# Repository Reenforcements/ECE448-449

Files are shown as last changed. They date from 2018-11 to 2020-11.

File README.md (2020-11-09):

# Reconfigurable Pinball Machine

#### [Final_Report.pdf](https://github.com/Reenforcements/ECE448-449/blob/master/Final_Report.pdf)

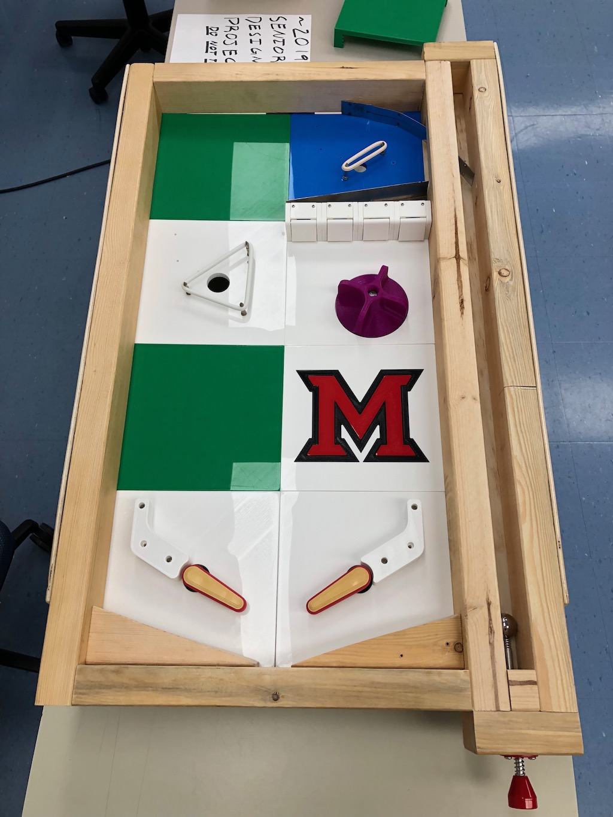
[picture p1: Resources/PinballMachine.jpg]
Pinball machine


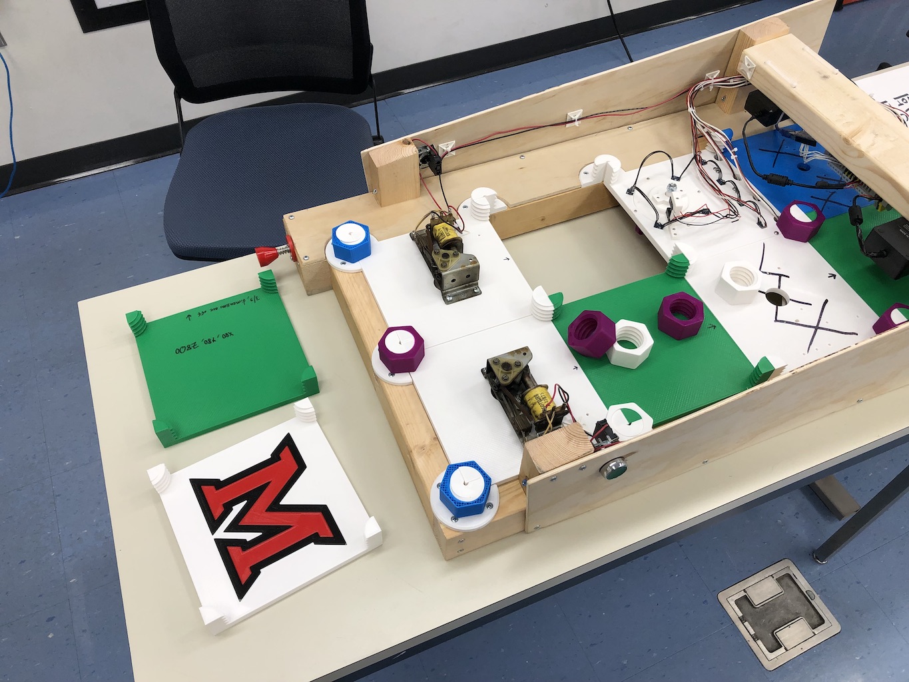
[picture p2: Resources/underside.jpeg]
Underside of the machine


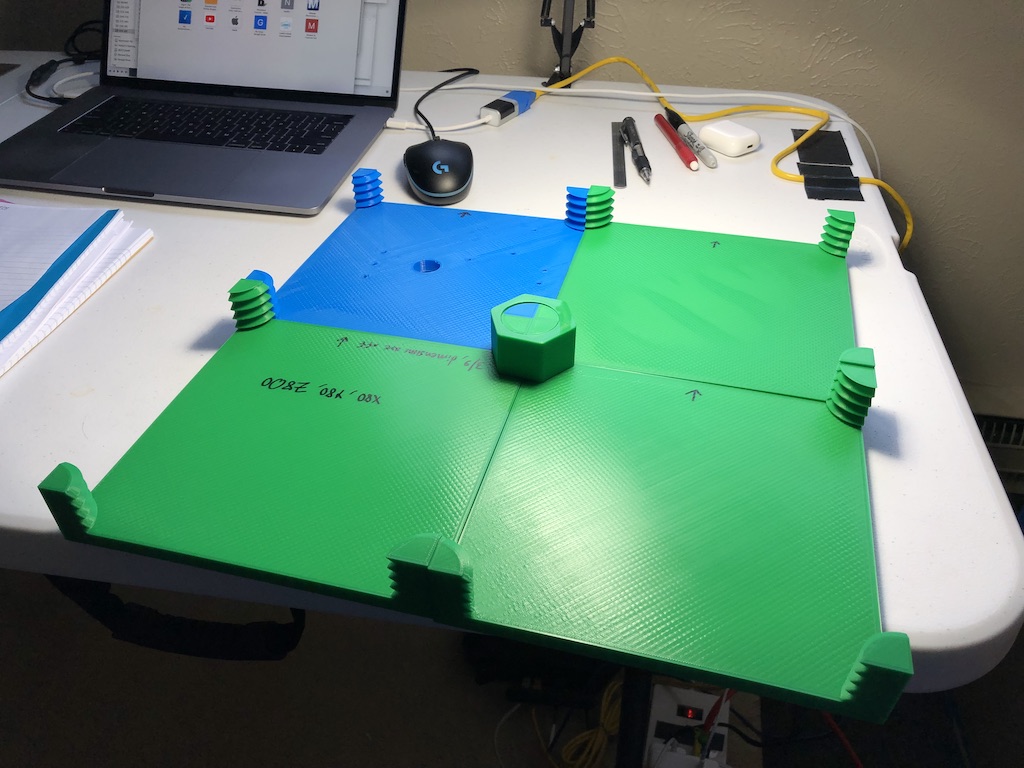
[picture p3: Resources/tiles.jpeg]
Tile connectivity


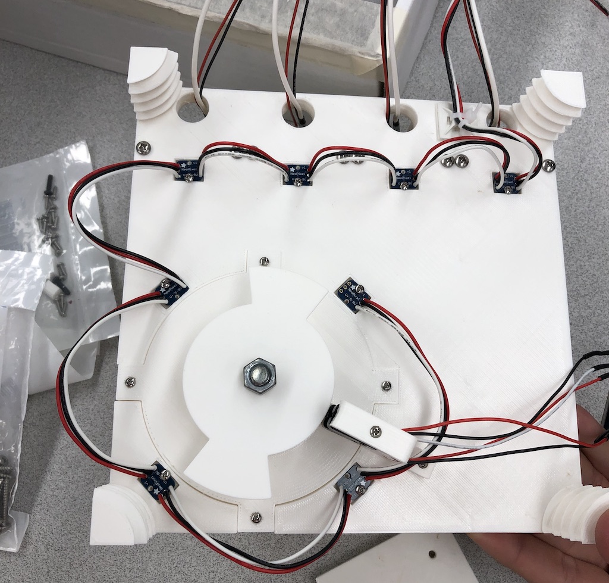
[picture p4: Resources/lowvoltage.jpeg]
Low voltage tile


This is a research project for a reconfigurable pinball machine for senior design at Miami University.

#### Team Members:
- Austyn Larkin
- Kyle Nichols
- Scott Nicholson
- Storm Nicholson

#### Adviser:
Dr. Jamieson

## CADFiles

The CADFiles folder holds 3D printable STL files of the current CAD design.

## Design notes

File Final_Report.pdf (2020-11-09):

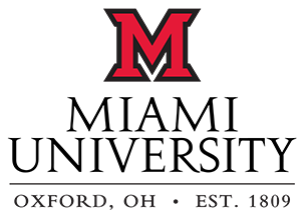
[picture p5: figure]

## Pinball Machine Design Project ECE 449

## Austyn Larkin Kyle Nichols Scott Nicholson Storm Nicholson

## Advisor: Dr. Jamieson

### 1. Intro/Problem Definition

Pinball machines are a type of arcade game. In pinball, the goal for the player is to

control the ball with flippers at the bottom of the play field. Each element in the game has a

specific point value associated with it. When the ball hits/touches/rolls over the scoring point,

that specific amount is added to the players overall score. Pinball machines cost thousands of

dollars to build and because of the fairly static play area, they can suffer from poor replayability.

The goal of this project is to design a reconfigurable pinball/arcade machine. The

question is; how reconfigurable can the machine be and what tools are needed to create the

framework for such a machine. Reconfigurable can mean many different things. Some of the

options discussed were changing the playfield in between games, changing the playfield while

the game is being played, and having different game modes within a menu. These ideas will

allow the game to be changed either physically and/or electronically to alter gameplay. From a

player’s perspective, this will help to keep the game fresh and new. From an arcade owner’s

perspective, reconfigurability enhances replayability at minimum cost, thus increasing revenue.

### 2. Project Background

A pinball machine consists of (at minimum) the following components: pinballs, flippers,

a plunger, and a play area with scoring points and for the ball to roll around on, bump into,

activate, etc. The play area contains a variety of play elements to enhance gameplay such as:

bumpers, lights, targets, holes, and carousels. Each of these components is described in detail

below.

- Pinballs (Figure 2.1) are metal spheres with a nominal diameter of 1 ” and ¹
16
weigh 2 oz. They’re used as the main playing piece in the game. 8

7

Figure 2.1 - A Pinball

https://www.amazon.com/WE-Games-Replacement-Steel-Pinball/dp/B004AA2ZD6

- Flippers (Figure 2.2) are levers which are controlled by the player, to hit the ball

in the direction desired by the player. Each flipper is covered in rubber so that the

pinball bounces off of it and is controlled by a button on the side of the machine.

The buttons activate solenoids underneath the playfield, which move the flippers.

The flippers in our design require a 24V 5A DC power supply as per specs found

on the manufacturer's website.

Figure 2.2 - Pinball Flippers

https://pinside.com/pinball/machine/f-14-tomcat

- The plunger (Figure 2.3) is used by the player to launch a new ball into the play

area. The plunger consists of a handle that is pulled outwards towards the player.

Pulling the handle out stretches a spring around the plunger’s axle. When the

player releases the plunger, the spring recoils and launches the ball located in

front of it into the play area.

Figure 2.3 - Pinball Plunger

https://www.pinballlife.com/stern-ball-shooter-assembly.html

- The playfield is defined as the region in which the pinball moves (Figure 2.4). It

contains the flippers as well as other play elements mentioned above. To keep the

game going, the player has to ensure the ball doesn’t leave the playfield.

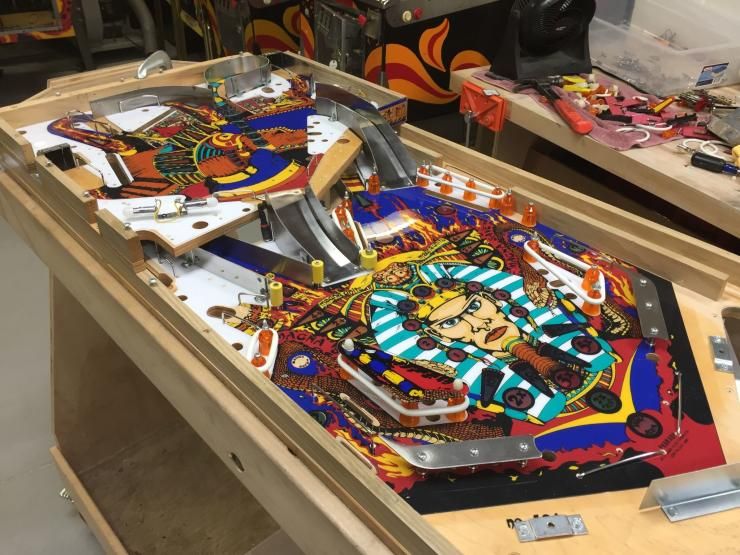
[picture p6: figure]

Figure 2.4 - The Pinball Playfield

http://www.pinballgifts.com/store/p75/Pinball_Playfield_Hardtop.html

- Bumpers come in multiple styles and include solenoids that use an array of

different voltages. An example of a circular pop bumper is shown in Figure 2.5. If

the pinball makes contact with the lower ring of the bumper, the solenoid is

activated. The solenoid pulls the upper ring of the bumper down onto the pinball

which causes the ball to ricochet away from the bumper.

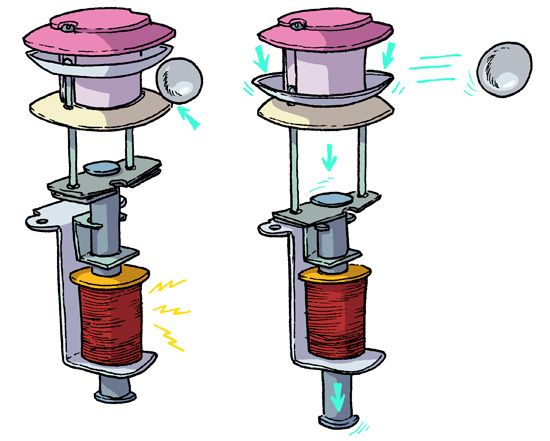
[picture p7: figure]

Figure 2.5 - An illustration of how a pop bumper works

http://droptargetzine.blogspot.com/2013/02/revisited-illustration-4-pop-bumper.html

### 3. Project Research

The first step in making our reconfigurable pinball machine was to define what

reconfigurable meant. In our case, we defined reconfigurable to be, any change to the machine in

order to alter the gameplay. In theory, this could be done both physically and through software.

We decided to explore the physical route, meaning that we would try to design a machine in

which the playfield could be rearranged, changed or entirely replaced.

To accomplish this, the play area is divided into a grid of tiles. Each tile would be a

square of material (either wood or 3D printed). Each tile contains its own unique set of play

elements. Tiles are joined together to ensure the ball rolls smoothly across the joints. The tiles

could be easily detached from one another to allow them to be interchanged. As each tile is

unique, the interchanging of tiles would allow the owner to alter how game looks and is played.

An early sketch of a single tile is shown in Figure 3.1.

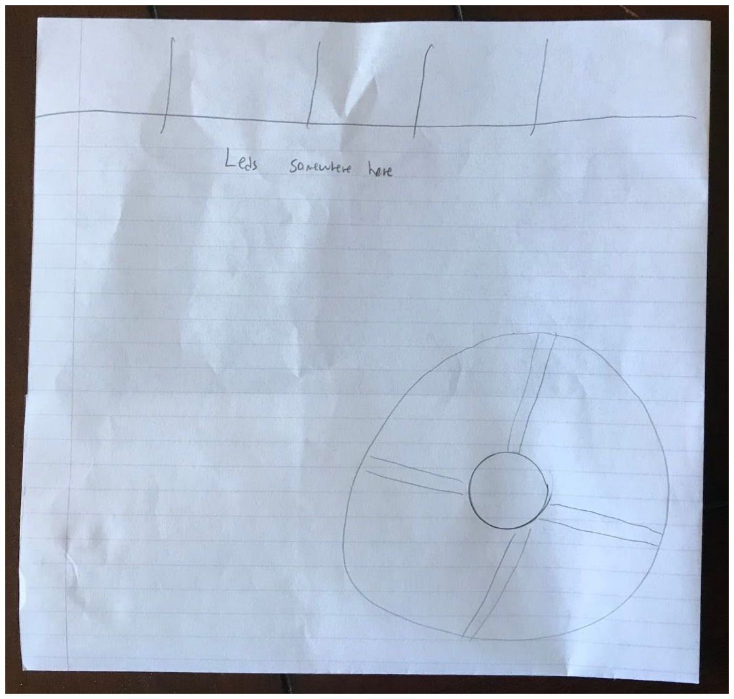
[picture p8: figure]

Figure 3.1 - An early sketch of a single tile

The tile in Figure 3.1 has three separate play elements. The circle in the bottom right

corner is the carousel. As the carousel spins, points could be added to the player’s score, thus the

goal is to keep the carousel spinning for as long as possible. The divisions at the top were coined

“bingo boxes”. These boxes have doors on the front that when hit by the ball, trigger the switch inside. LEDs are embedded throughout the tile to give feedback to the player. To create a fully

reconfigurable pinball machine, a variety of these tiles could be created and linked together to

form the playfield. As long as the tiles are kept to our specified size of 20x20cm, they can

contain any play elements in any combination.

This tile based system poses several potential issues such as ensuring the tiles link

together smoothly. If the height of the surface of one tile does not match up with the others, then

the pinball would not be able to roll smoothly across them. Another issue is, how do we actually

link multiple tiles together? Tiles would need to be linked together tightly to prevent shifting

during gameplay.

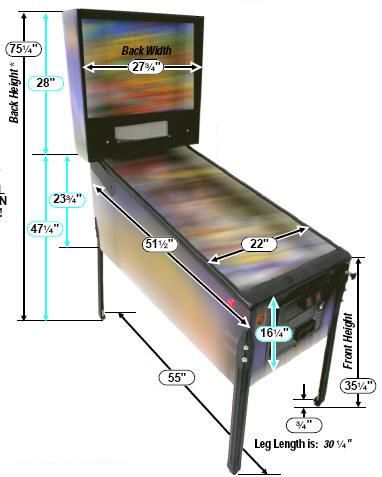
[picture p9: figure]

Figure 3.2 - Common Machine Dimensions

http://www.castleclassicarcade.com/archives/game-dimensions

When researching the components for this project, we found that the cost of building a

full size machine would put us way over our $150 budget. The full size budget is determined by

using the dimensions in Figure 3.2 (above). Once we had the dimensions, we were able to

estimate the amount of tiles a full machine would need to include, which would be around 20.

We estimated the average cost of making a basic tile to be approximately $45. A basic tile

included the cost of one or two playfield elements, screws, wiring and the material of the tile

itself.

After totaling the cost for a full size machine, the decision was made to scale our design

back. We decided that building a single basic tile, like the one previously described, as a demo

was a more achievable task. Doing such would keep us within budget and would also give us a

chance to prove that we are capable of replicating the demo tile to complete a full scale machine.

Quantity | Part Name | Price | Description/Purpose
1 | Plunger | $21.95 | Launches the ball into play
2 | Flipper Buttons | $0.00 | When pushed, a flipper will activate
2 | Flippers | $31.15 | Hits the ball around the playfield
1 | 24V-5A power supply | $16.99 | Power for the flippers
1 | 5V-6A power supply | $14.88 | Power for the Arduino
5 | Plywood sheets | $18.99 | For the outermost layer
2 | 2x3s | $4.99 each | For mounting the tiles to the edges
40 | Mini Post Screws | $1.00 each | Protects the corners of the bingo boxes
10 | 3 inch rubber rings | $0.95 each | For the lanes next to the flippers
10 | Rubber post cover | $1.20 each | To protect the front of the bingo boxes

2 | Metal siding | $10.53 each | Cover the edges of the machine
1 | #8 2-1/2” wood screws | $11.49 Pack of 100 | To attach the wood to each other
1 | #8 ⅝” pan head screws | $4.89 Pack of 100 | Attaching the metal siding to the machine

Table 3.1 - Break down of the parts and the associated costs for the scale machine.

The total cost of parts and building materials for the machine came to $319.99. This total

only reflects the list price of the items, meaning the tax and shipping costs are not included.

Additional machines could be built at a lower cost due to excess supplies saved from the initial

build.

### 4. Solution Process

For the demo tile (shown in Figure 4.1) we decided to include two scoring points: first

the carousel and second the bingo boxes. Visual feedback in the form of LEDs is triggered when

a point is scored. The score is increased when the player hits the pinball onto the door of the

bingo box or when the carousel is spinning.

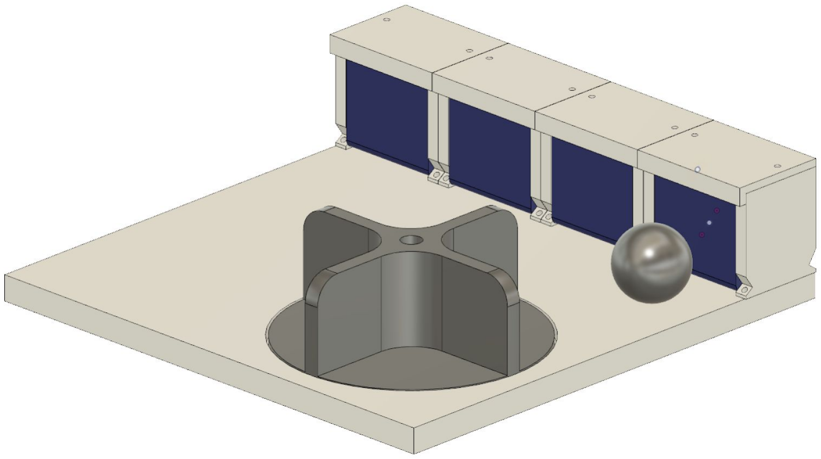
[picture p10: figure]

Figure 4.1 - An early 3D CAD drawing of the demo tile

The demo tile is 20x20 cm and 1 cm thick. The carousel is the round, gray object in the

foreground. The four boxes in the back with the blue doors are referred to as bingo boxes. A

pinball (actual size) is also included for scale.

Snap action switches are located inside the bingo boxes and are triggered by the door of

the box. When the switch is activated, the circuit is closed and sends a high signal to the

Arduino. The carousel is attached to an optical chopper, this chopper spins in tandem with the

carousel and is the part which actually breaks the beam of the sensor. The state of the sensor

changes from “broken” to “unbroken” as the carousel spins.

In order to attach tiles together, a linking mechanism was devised using threaded posts.

Figures 4.2, 4.3 and 4.4 below show a prototype of how the corners of four tiles will link. Here,

it is important to realize that the pieces in the photos are not full tiles, but only the corners of

what would be full tiles in practice. Each tile corner contains a fourth of a threaded post (Figure

4.2). When four tiles are placed adjacent to one another inside the pinball machine, their corners

will align to form a full threaded post (Figure 4.3). A large 3D printed nut is then placed on the

threaded post and fastened down. This nut not only holds them together but also keeps the tiles

level with one another (Figure 4.4).

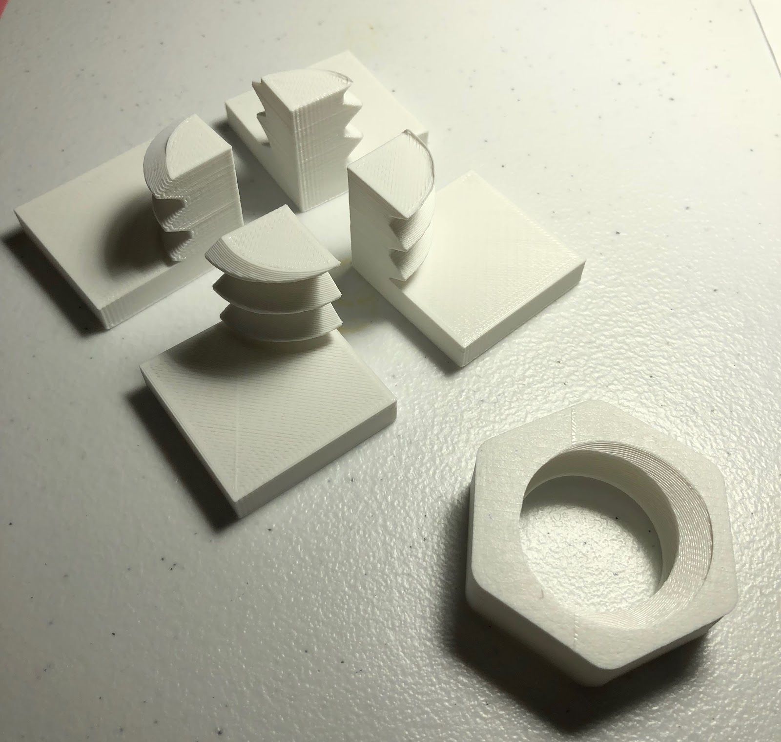
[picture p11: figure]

Figure 4.2 - Unlinked tiles (bottom view)

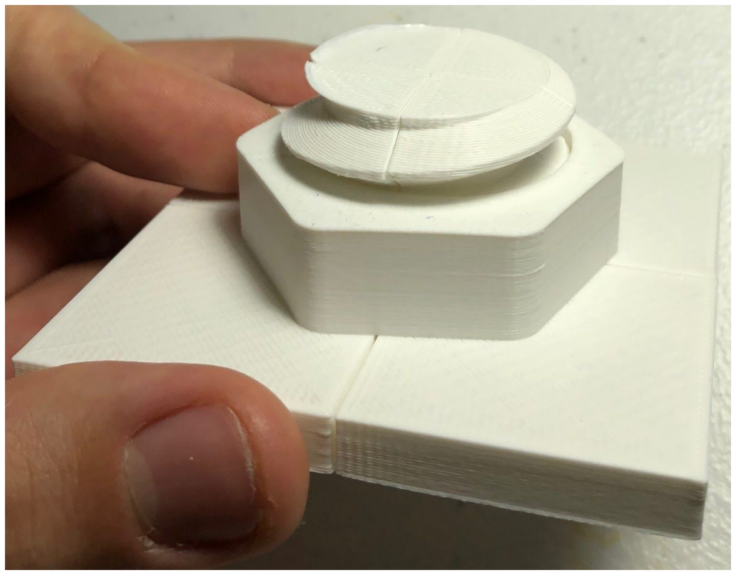
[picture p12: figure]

Figure 4.3 - Linked tiles
(bottom view)

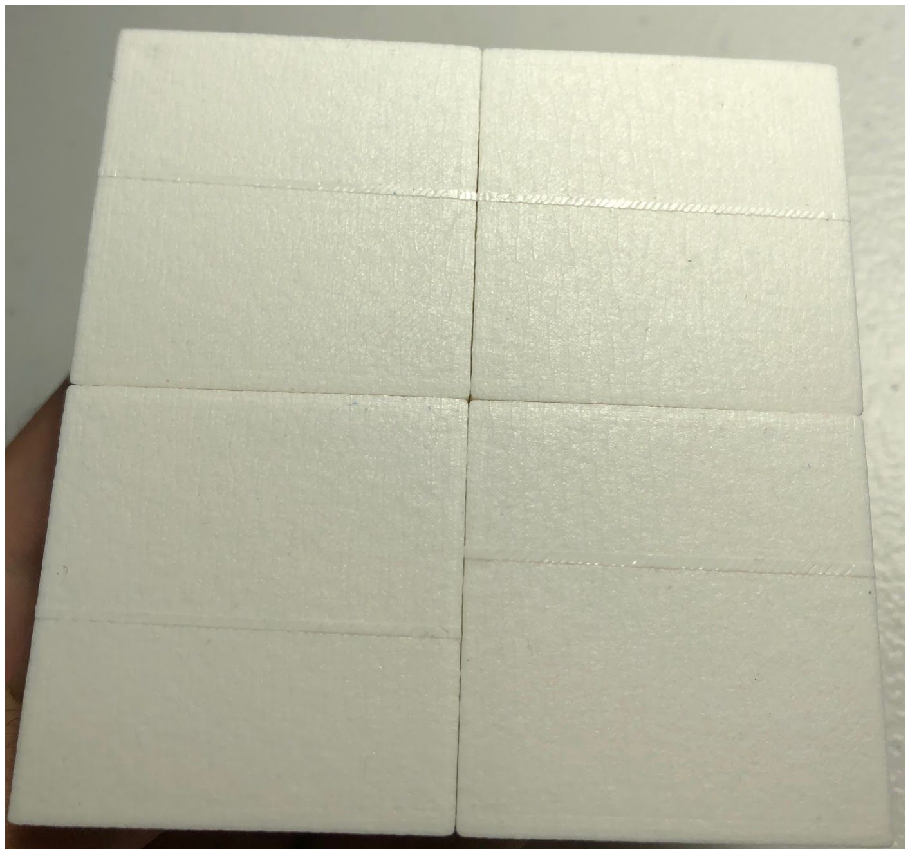
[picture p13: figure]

Figure 4.4 - Linked tiles
(top view)

Three-dimensional printing was chosen as the method of manufacturing the tiles and

some of the playfield elements. Three-dimensional printing provides relatively robust, fast, and

cheap way of prototyping. Numerous materials are available for use in 3D printers, but

Acrylonitrile butadiene styrene (ABS) plastic was chosen to give the parts the best chance of

surviving a collision with a heavy pinball. Printing ABS is more challenging than less strong

alternatives. ABS is sensitive to temperature and tends to shrink dramatically as it cools. In order

to achieve best results, the 3D printer was fitted with a glass bed (Figure 4.5). This ensures that

the plastic sticks to the bed as the printer prints.

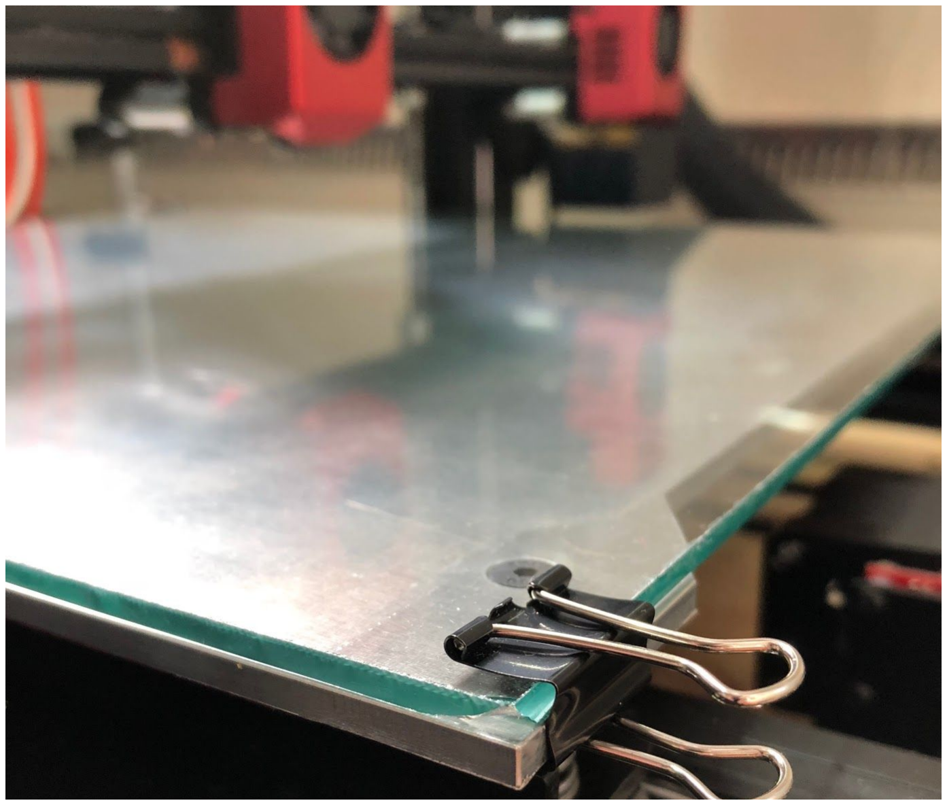
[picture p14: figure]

Figure 4.5 - The 3D printer outfitted with a glass print bed

Even with a glass bed, numerous print issues were encountered. One such issue was layer

shifting (Figure 4.6). Layer shifting can occur if a stepper motor skips a step or if something on

the 3D printer physically shifts during the printing process. Though the layer shifting hasn’t been

completely solved, lowering the movement acceleration of the printer helps.

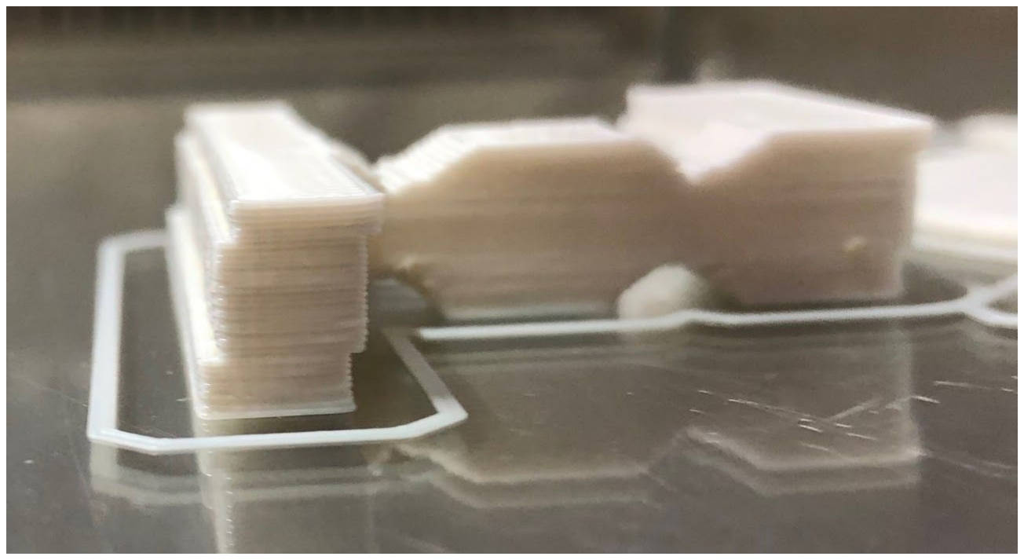
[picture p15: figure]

Figure 4.6 - Layer shifting can be seen along the left wall of the print, which is supposed to be a

straight up and down

Ultimately, the printing material was switched from ABS to PLA (polylactic acid.)

Although PLA is not as robust as ABS, it tends to print with fewer layer shifts and far less

warping. This switch resulted in flatter prints (Figure 4.7) and an increased print success rate.

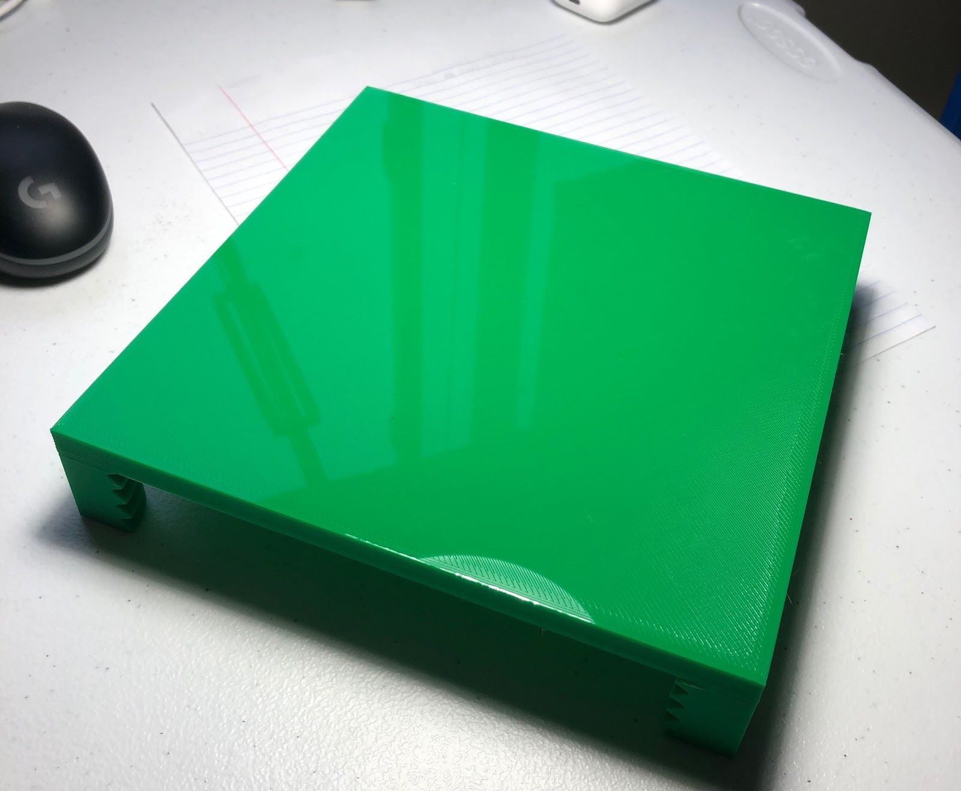
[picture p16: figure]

Figure 4.7 - A blank tile printed from PLA. The tile exhibits very little shrinking and curling,

making it much flatter than a tile printed from ABS

### 5. Final Results

The final proof-of-concept machine can be seen in Figures 5.1 and 5.2, below. The

machine is made up of eight tiles in total: two flipper tiles, two blank tiles, two passive bumper

tiles, a "Miami" tile and an updated version of the demo tile. In order to mount the tiles to the

machine, permanent screw-on mounts were developed to mate with the sides and corners of tiles

(Figures 5.3 and 5.4).

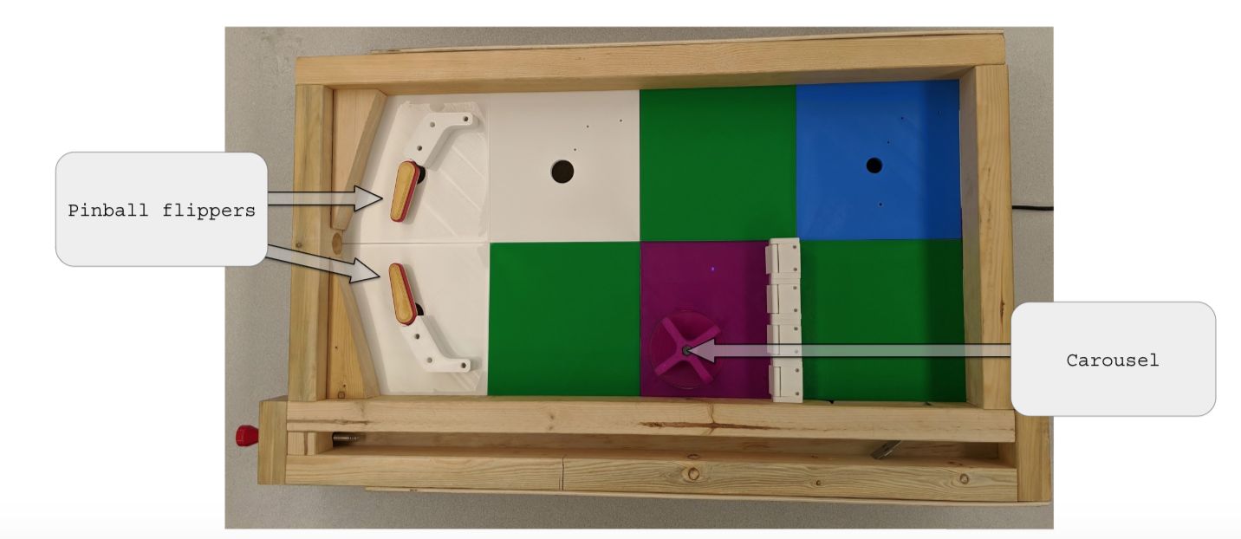
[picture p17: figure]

Figure 5.1 - Functioning scale prototype machine

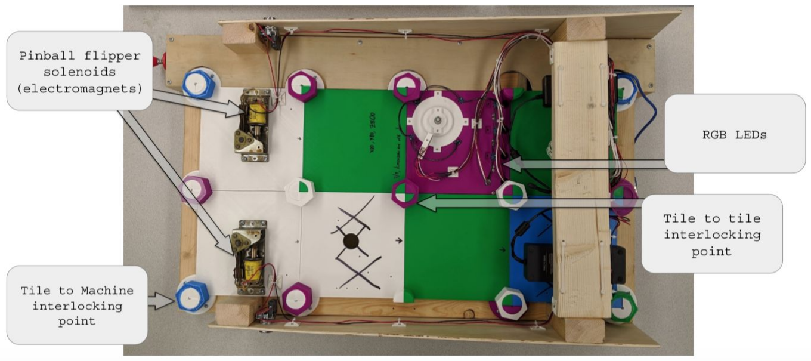
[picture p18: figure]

Figure 5.2 - The underside of the prototype machine. Corner and side mounts are visible along

the outer edges of the tiles

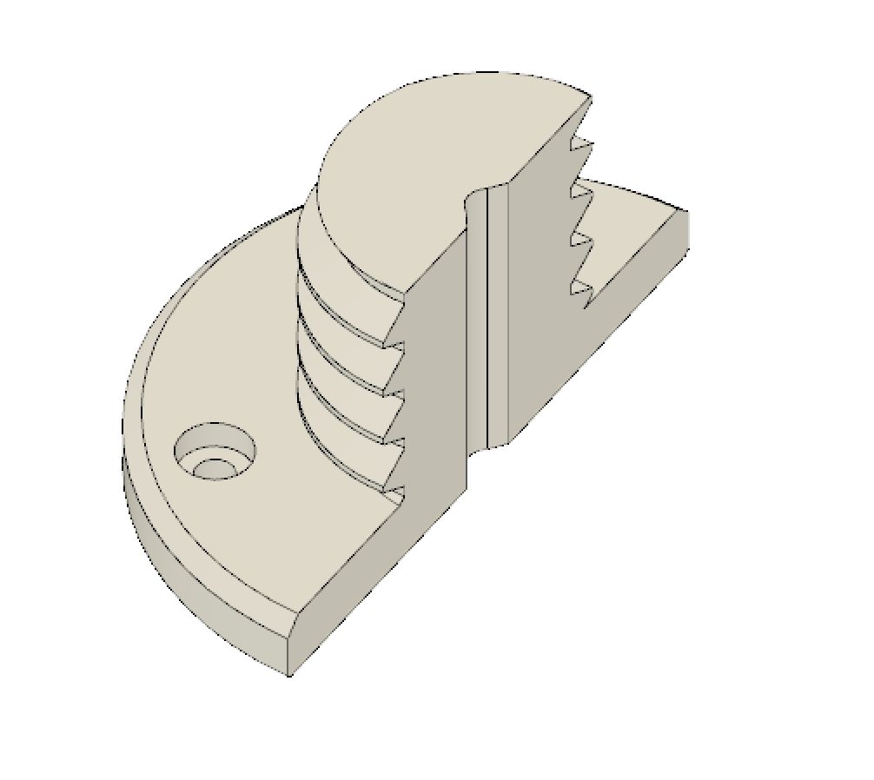
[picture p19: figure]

Figure 5.3 - Corner mount | Figure 5.4 - Side mount

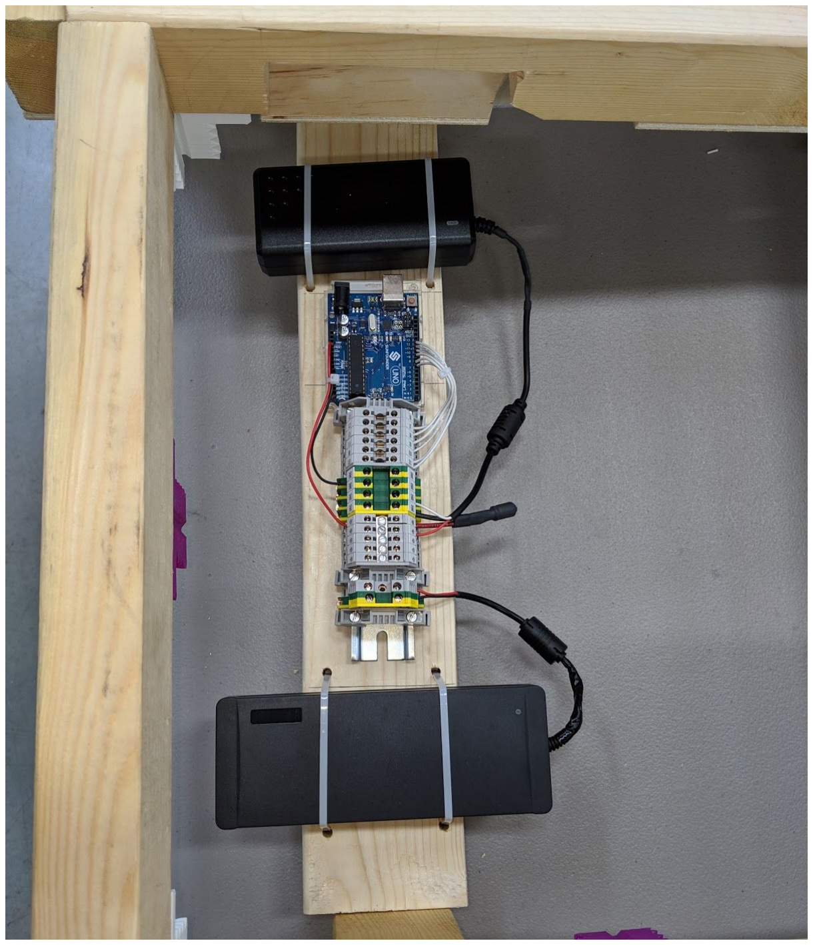
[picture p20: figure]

Figure 5.5 - Mounted power supplies, Arduino and wire terminals under the machine

The flipper tiles contain actual pinball machine flippers that were salvaged from an old

machine. Each flipper tile was built to accommodate the left and right flipper and a fastened-on gutter (Figure 5.6). The blank tiles are plain tiles and contain no electronics (Figure 5.7). The

passive bumper tiles are repurposed flipper tiles which were printed incorrectly, this was done in

order to conserve resources (Figure 5.8). The Miami tile is a stylized version of the blank tile to

show that designs and logos can be incorporated into the design (Figure 5.9). It serves the same

purpose as a regular blank tile, but has inset pieces of plastic that recreate the Miami logo.

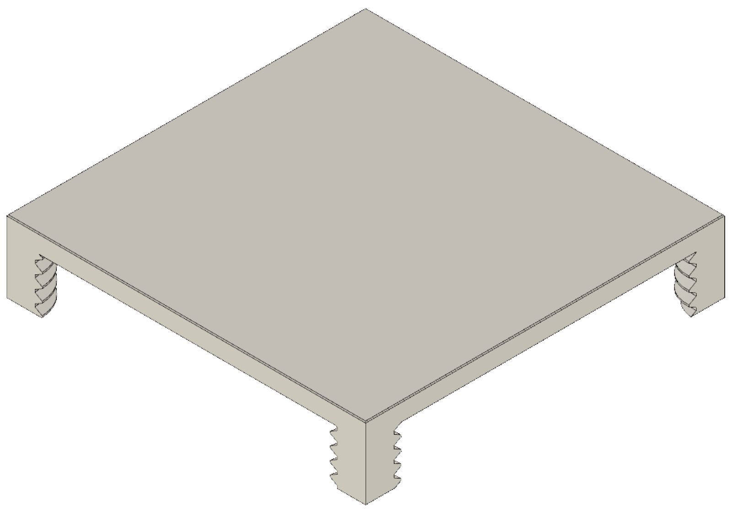
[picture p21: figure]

Figure 5.6 - The right flipper tile (active) Figure 5.7 - A standard blank tile (passive)

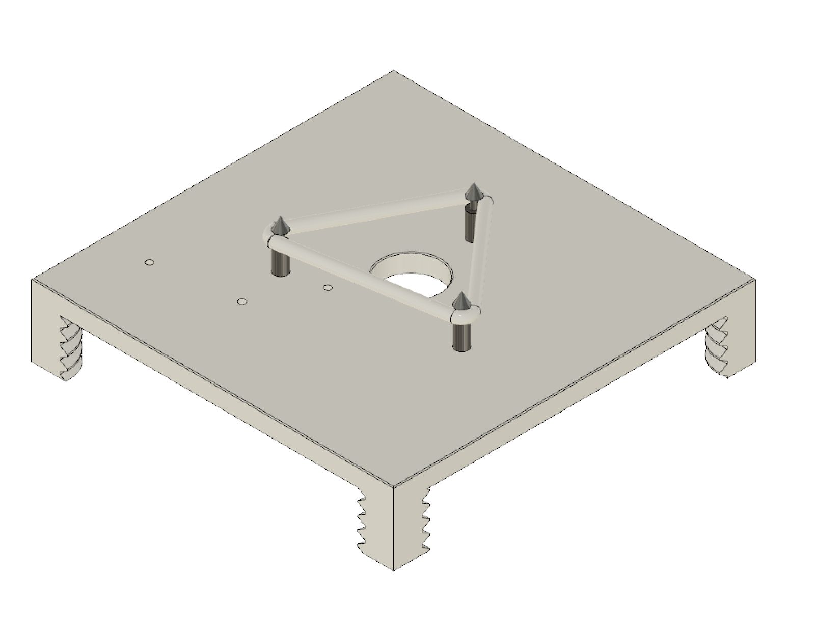
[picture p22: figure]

Figure 5.8 - The repurposed flipper tile

(passive)

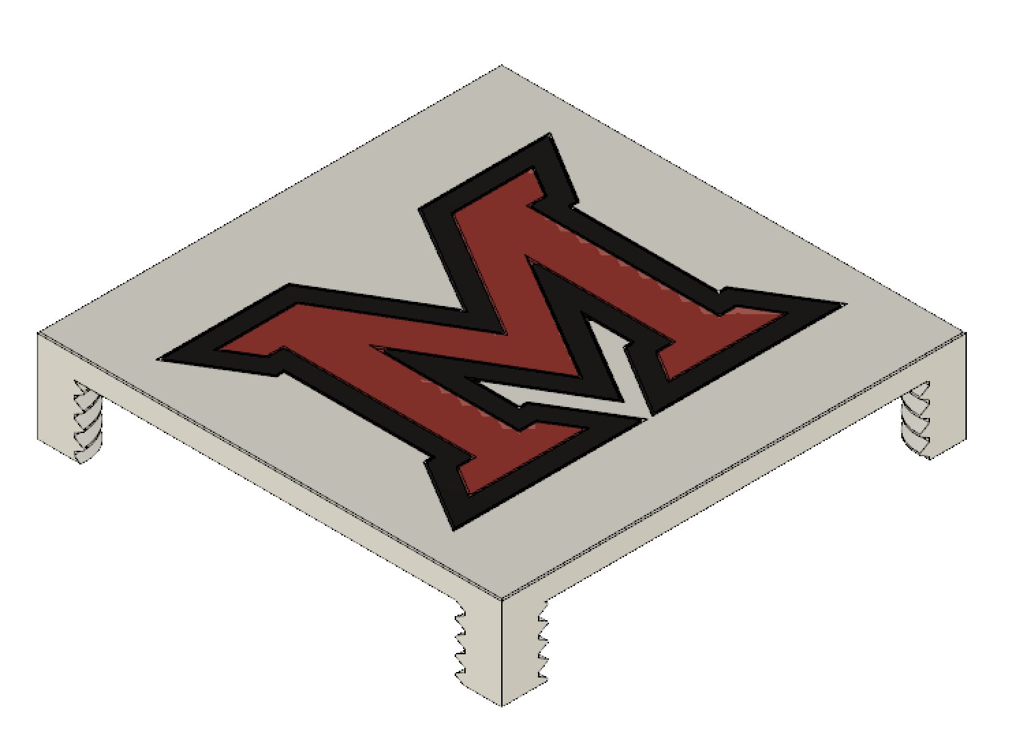
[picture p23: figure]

Figure 5.9 - The Miami “M” tile (passive)

The demo tile, which is the only low voltage tile, can be seen in Figure 5.11. The tile and

its structure consists of 3D printed, plastic parts. Individual pieces are held together with various

sized screws, this provides strength and replacement part interchangeability. The tile contains a

multitude of electronics that support sensing the ball’s action and giving feedback to the player

(Figures 5.10 and 5.12). The break-beam sensor can be seen in the foreground of Figure 5.12 (the

two black rectangles). The optical chopper, which breaks the beam, is the part that looks like a

blade (directly underneath the nut). The holes in the far back of the tile lead into the bingo boxes

where switches are fastened with screws.

A 5V 6A DC power supply was selected for this project as the Arduinos standard

operating voltage is 5V DC. Below is a table of the max current drawn from this circuit at

maximum (all elements on). During normal operations the current draw will be significantly

lower than this maximum calculation as not all of the elements will be in use at the same time.

The 6A power supply could support approximately three tiles, given that the components of

those tiles draw current similar to the demo tile.

Component | Max Current Draw
Arduino | 1000mA
Each Arduino I/O pin | 40mA x 4 = 160mA
Each LED | 55mA x 8 = 440mA
Break Beam Sensor | 20mA
TOTAL | 1,620mA = 1.62A
Table 5.1 - Maximum current drawn by the demo tile

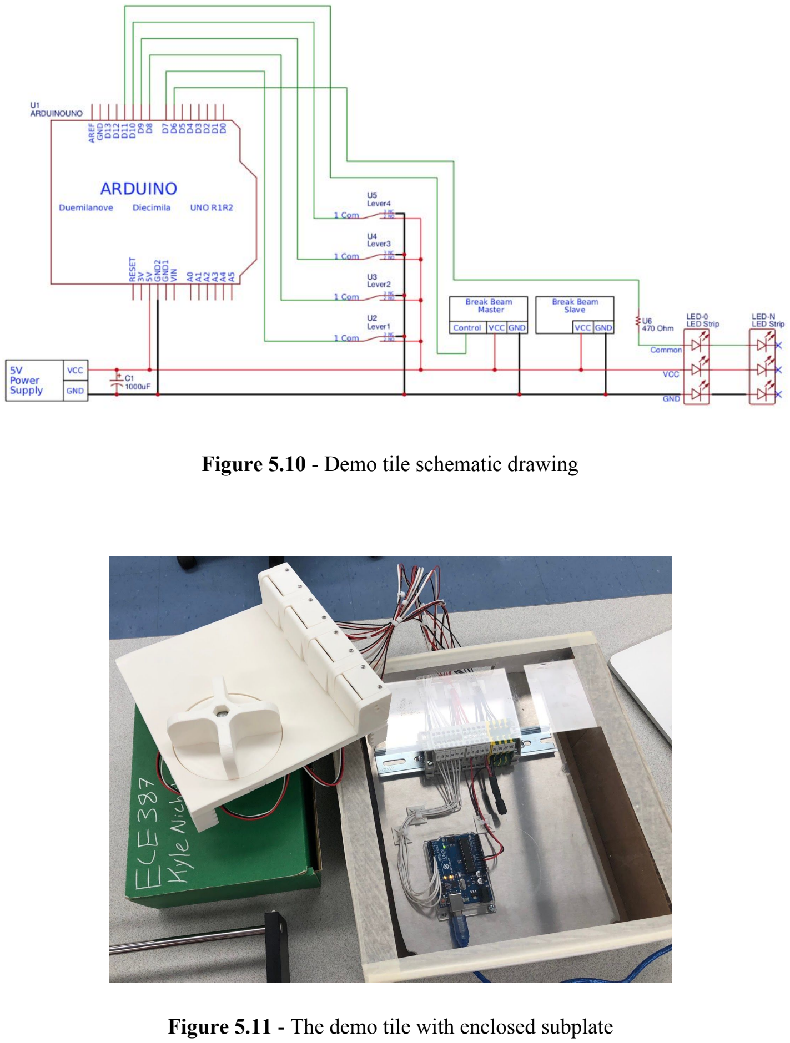
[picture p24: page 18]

Figure 5.10 - Demo tile schematic drawing

Figure 5.11 - The demo tile with enclosed subplate

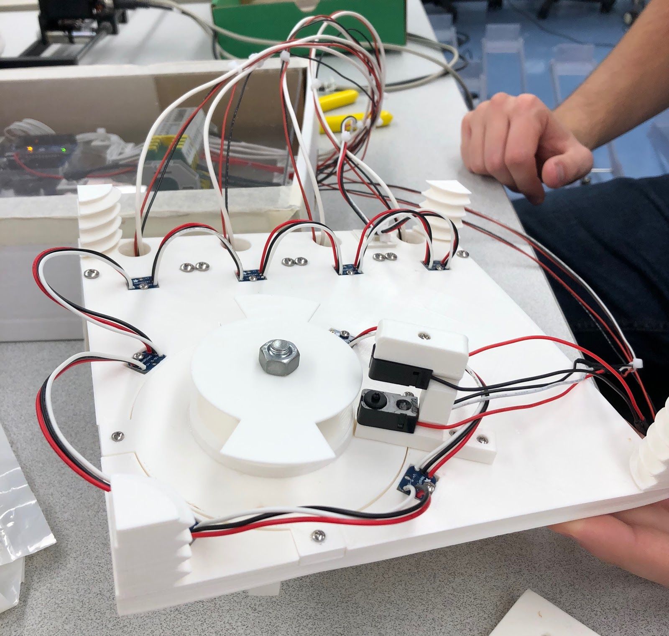
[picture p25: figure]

Figure 5.12 - Underside of the demo tile

For the demo tile, we decided to implement addressable LEDs in order to conserve the

Arduinos IO pins. The LEDs chosen are Adafruits’ RGB smart Neopixels, which can be stranded

together and controlled by just one IO pin. These LEDs only use a max (full brightness on white

light) 55mA of current. With eight LEDs, that's a max current draw of 440mA from the LEDs.

The LEDs can be seen above (Figure 5.12), they are the regularly spaced rectangles embedded

into the underside of the tile.

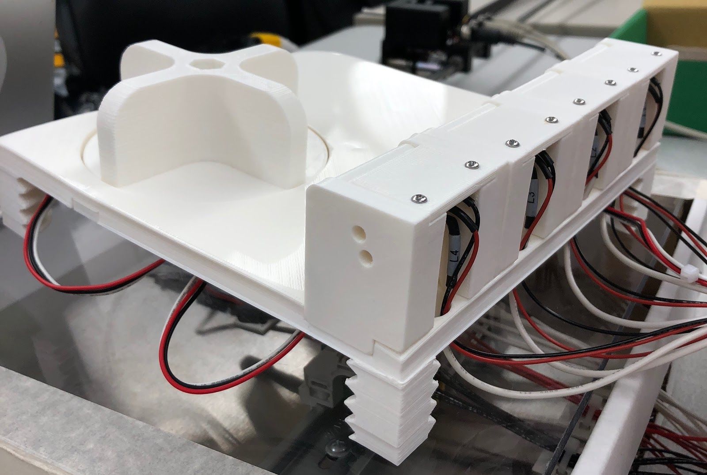
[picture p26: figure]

Figure 5.13 - The back of the demo tile

The coding, which detects when the ball hits the bingo boxes, was done in the Arduino

IDE. The door of the bingo box activates a limit switch when it is compressed. When the

Arduino receives this high signal from the switch, it then activities the corresponding LED. The

Arduino code can be seen below.

#include <Adafruit_NeoPixel.h>

#ifdef __AVR__

#include <avr/power.h>

#endif

// pinouts
#define LED 6

#define L1 11

#define L2 7

#define L3 8

#define L4 9

#define BB 10

// defines how many lights are in the strip.
// first light is addressed to 0.
#define NUM_LEDS 8

#define BRIGHTNESS 100 // range from 0-100

Adafruit_NeoPixel strip = Adafruit_NeoPixel(NUM_LEDS, LED, NEO_GRB + NEO_KHZ800);

void setup() {
// initializes the serial print
Serial.begin(9600);

// initialize the LED strip strip.setBrightness(BRIGHTNESS); strip.begin();
strip.show(); // initialize all pixels to 'off'

// initialize the sensor pin as an input pinMode(BB, INPUT);
digitalWrite(BB, HIGH); // turn on the pull up

// initialize the limit switch pins
pinMode(L1, INPUT);
pinMode(L2, INPUT);
pinMode(L3, INPUT);
pinMode(L4, INPUT);
}// end setup

void loop() {
//======================================= L1 if(digitalRead(L1) == HIGH){
Serial.println("PIN 1");
// sets the LED to a color
// the first input is the number of the LED then the color strip.setPixelColor(3, strip.Color(0,255,255) ); strip.show();
// waits for 280 milliseconds
delay(280);
// sets the LED to black ie. turns the LED off strip.setPixelColor(3, strip.Color(0,0,0) );
strip.show();
}
//======================================= L2 if(digitalRead(L2) == HIGH){
Serial.println("PIN 2");
strip.setPixelColor(2, strip.Color(255,0,0) ); strip.show();
delay(280);
strip.setPixelColor(2, strip.Color(0,0,0) );
strip.show();
}
//======================================= L3 if(digitalRead(L3) == HIGH){
Serial.println("PIN 3");
strip.setPixelColor(1, strip.Color(255, 20, 147) ); strip.show();
delay(280);
strip.setPixelColor(1, strip.Color(0,0,0) );
strip.show();
}
//======================================= L4 if(digitalRead(L4) == HIGH){
Serial.println("PIN 4");
strip.setPixelColor(0, strip.Color(0,255,0) ); strip.show();
delay(280);
strip.setPixelColor(0, strip.Color(0,0,0) ); strip.show();
}
} // end main
Table 5.2 - Arduino code

For the final design of the demo tile, a few changes were made. First, when the machine

was assembled and tested, we observed that the ball would get stuck on a carousel during

gameplay. Thus the carousel was redesigned to include loose ball bearings (BBs) in a track

underneath, giving it less resistance when the ball was on top of it. The base of the carousel was

also given a slight "conic shape" to ensure the ball rolls off. Secondly, the position of the carousel was moved closer towards the center of the tile as the ball would get wedged between

the wall of the machine and the carousel. The final carousel design can be seen in Figures 5.14

and 5.15.

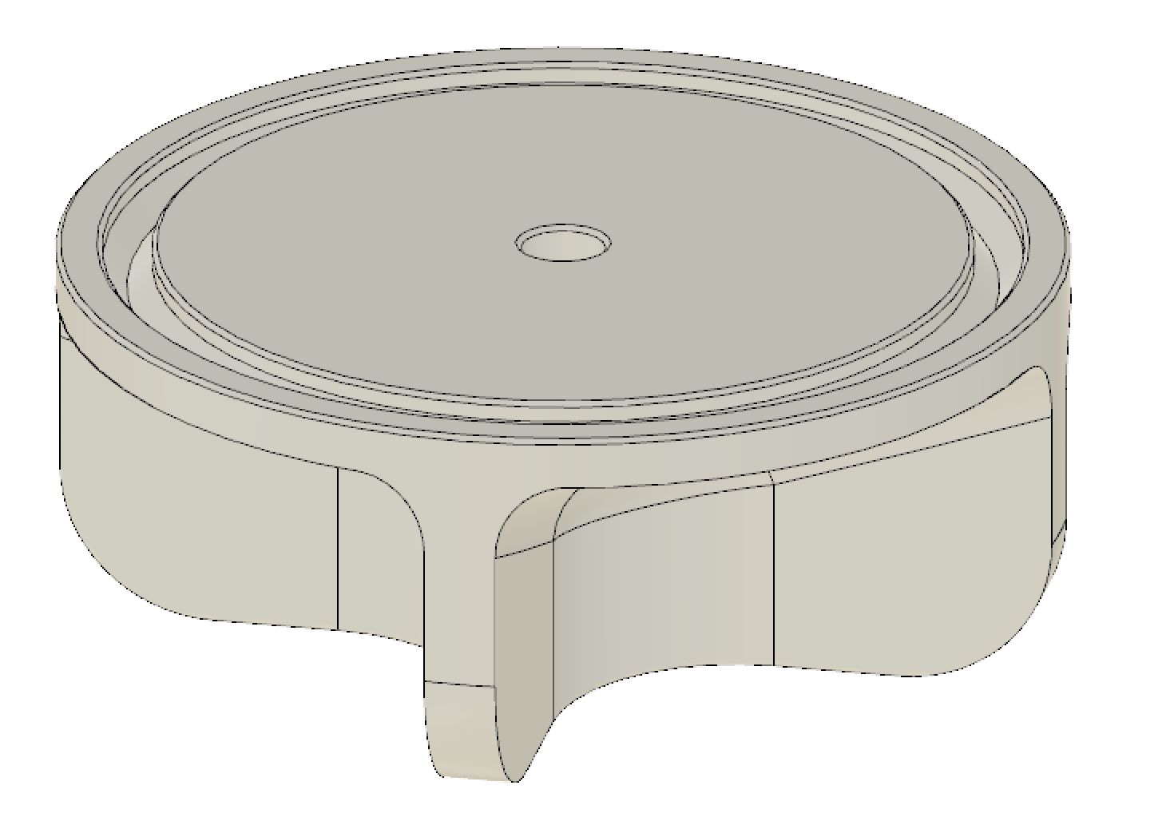
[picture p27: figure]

Figure 5.14 - Carousel (bottom view) - the ridge along the edge is where the BBs would be

placed

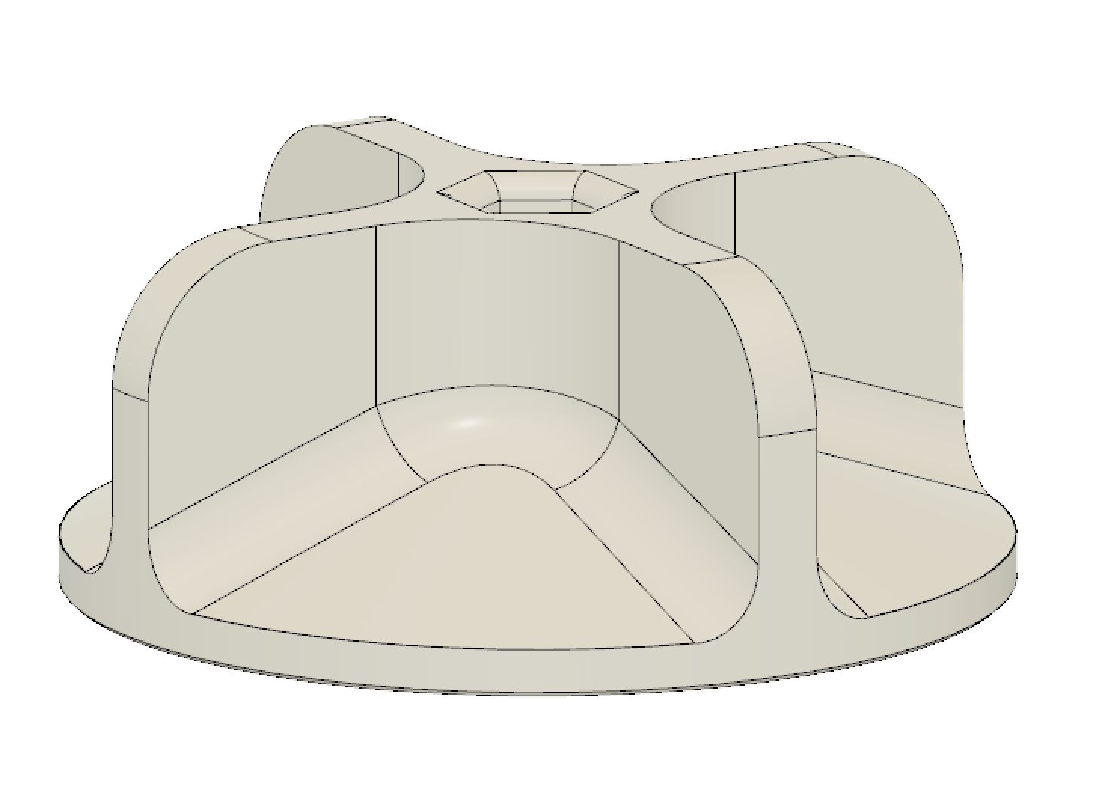
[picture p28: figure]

Figure 5.15 - Carousel (top view) - the conic shape of the base can be seen

### 6. Future Work

Feedback is the most necessary tool for improvement and after experiencing the building

of the machine and presenting it at the Senior Design Expo, there were many questions raised

that were constructive to the machine as it stands and what it could become. This feedback along with ideas our group had as we were building the machine led to an ideal picture on where this

project could go.

To start with an idea for gameplay, we were asked frequently how the machine keeps

score and as it stands right now, the machine does not keep score. The LEDs for the bingo boxes

are run on an arduino and a scoreboard can be run just as easily. In fact, it is as simple as

hooking up an LCD to the arduino and coding that every time a LED light is turned on by being

hit, the score will go up by a certain amount, depending on the bingo box hit.

In addition to keeping score, there would need to be a way to reset the score for each new

game. This could be triggered when the pinball falls out of play and into the holding area.

However, as the design stands there is nothing stopping the player from picking up the ball

before it reaches the holding area. Adding plexiglass, to cover the playfield, would solve this

problem. Adding plexiglass will also improve the overall safety of the machine because the ball

will not be able to escape the play field and the hands/ fingers of players will never come into

contact with the playfield parts.

A suggestion given to our group at the expo was to design the next version of the

machine to accepting cash, coins, or even MULAA. In this scenario, every part of the machine

would need to be contained to order to avoid loss of potential profits. In addition to plexiglass, a

ball return system would need to be implemented in order for the system to only release a ball to

those who have paid. Furthermore, like typical pinball machines anti-cheat systems, like anti-tilt

gyros would have to be put into place to keep players honest.

A design question that came up frequently during the design and build process but was

never resolved was; how the electrical elements should interact with each other. As it stands now, the flippers are independent of the arduino-run bingo boxes, but if the machine were to

continue developing there would likely be more electrical elements added. All of these new

components would have to communicate with arduino to keep score and to give feedback to the

player. This poses a problem as an Arduino has only so many IO pins. For future designs, a new

communication protocol would need to be explored to solve this issue.

The next concern we have is how the wiring will impact the configurability of the

machine. Right now, the top two tiles are sitting right above the terminals and power supplies

which makes removing them somewhat difficult. The solution to this is to make the cabinet

space inside the machine bigger, leaving more space to work and remove tiles.

This leads into the next consideration, of how the wiring of electrical elements might

affect the reconfigurability of the machine. As it stands now, when an active tile needs to be

replaced it would have to be completely dewired. While this process is not difficult, it is time

consuming and inefficient as mistakes could be made while rewiring. The solution to this would

be to add a pair of wire plugs in the wires between the Arduino and the tile. This system would

allow each tile to simply be unplugged and then be moved or removed.

Another design consideration that was questioned was to explore more 3D printing, not

just of the playfield tiles, but of the outside walls and alley way as well. This would be important

from a product reproduction standpoint because if the entire machine was 3D printable then the

cad files could be sold as a complete product. With more time and a bigger budget, this route

could be explored further.

The last consideration is in regard to gameplay. From a software perspective, the

possibilities are endless. We would suggest once all the hardware solutions are inplace, the future team should consult someone in the IMS department in order to make the best gameplay

possible. With more time, we would have liked to implement game modes into the machine.

These game modes, when selected, would automatically change the tiles in and out to create

different gameplay experiences on the same machine.

### 7. Ethics and Design Consideration

Engineers have a responsibility to protect any users of their products. As engineers on

this project, we are dealing with voltages higher than we typically have used in the past. Any

voltage can cause physical harm or death if not handled and wired properly. We have 24 Volts of

DC power in use for the flippers, and that voltage can cause harm if not wired correctly to begin

with. Another ethical responsibility come with the territory of improving upon an old product.

We do not want to squash the current pinball market by creating this new reconfigurable design.

This could displace workers within the current industry.

Lifelong learning is a valuable commitment to have as it allows a person to adapt and

stay up to date with current technologies. To be specific to engineering, engineers build

machines and implement solutions that replace the jobs and change the roles people have in

society. Those engineers create an environment which causes the need to adapt to a changing

world. Those people who practiced lifelong learning will have had developed new skills, not just

the skills they use every day, because of the desire to better themselves whether or not they

foresaw such an instance occurring. The skills learned can be technical, like knowing how to

build circuits, that can be transferred to different places now their current everyday skill-set is no

longer required or valuable. The most important aspect of lifelong learning is when learning itself, as a skill, is practiced and honed. There is nothing that a good learner cannot do because

even if they do not have skill set now, they can grow a skill set and remain a valuable asset and

that’s what lifelong learning is; being able to adapt to make the best life possible for yourself.

A broad education is valuable because it allows a single problem to be solved in many

different ways which results in a good solution being implemented. For this project specifically,

one of the first items to be thought about (not solved or implemented, thought about) was “what

does a configurable machine mean to you?” There are four members of the group and we had

four different ideas on what a “configurable machine” looked like. Eventually, the idea to make

the machine from movable tiles came out of this discussion and was the idea the group

implemented. This is an example on how different viewpoints, different educations, contribute to

engineering solutions, not just from one person but from a group of people. It is important broad

education occurs because it may be just a single person working on a solution, but with different

ways to tackle the problem, the best solution will be found and implemented. Basically, a broad

education creates a system of problem solving so all problems not just engineering that allows

for the best solution to be found regardless of how the circumstances of the problem change.

### 8. Conclusions

Creating a configurable pinball machine poses a significant design challenge. Different

aspects of a reconfigurable machine have been explored in regards to hardware. Ultimately, a tile

based design was chosen where the play area would be made of a grid of tiles. Tiles will come in

three different categories. The first type is the passive type which will not contain any

electronics. The second type is low voltage type which will contain at most LEDs and sensors.

The last tile type is the high voltage type which in addition low voltage electronics will contain

48V electronics such as flippers. As a proof of concept, a low voltage tile was created. The demo

tile was designed in CAD and 3D printed out of plastic. An Arduino UNO was used to control

the electronics on the tile.

That tile was then included into a small scale machine. This small scale machine is fully

functional, the player can launch the ball into play with the plunger and control the flippers via

the buttons on the side of the machine. The gameplay is simple, the player tries to hit the ball

into the bingo boxes to light the LED assigned to that box.

The next steps would be to design more low voltage tiles, decide how the tiles will

communicate with one another for scoring purposes and finally to build another model of the

machine to test these new configurations.

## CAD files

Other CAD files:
CADFiles/BallCatcher.f3d
CADFiles/Carousel-3.f3d
CADFiles/CarouselTest.f3d
CADFiles/DemoTile-3.f3z
CADFiles/DemoTile.f3d
CADFiles/DemoTile2.f3d
CADFiles/FineABSThreadTest.f3d
CADFiles/InterlockingGraphic.f3z
CADFiles/LEDFitTest.f3d
CADFiles/LEDHoleNegative.f3z
CADFiles/MiamiTile.f3d
CADFiles/PlainTile.f3d
CADFiles/Prototype1.f3z
CADFiles/SideMount.f3d
CADFiles/SideMountv2.f3z
CADFiles/TileFastener.f3d
CADFiles/TileLinkTest1.f3d

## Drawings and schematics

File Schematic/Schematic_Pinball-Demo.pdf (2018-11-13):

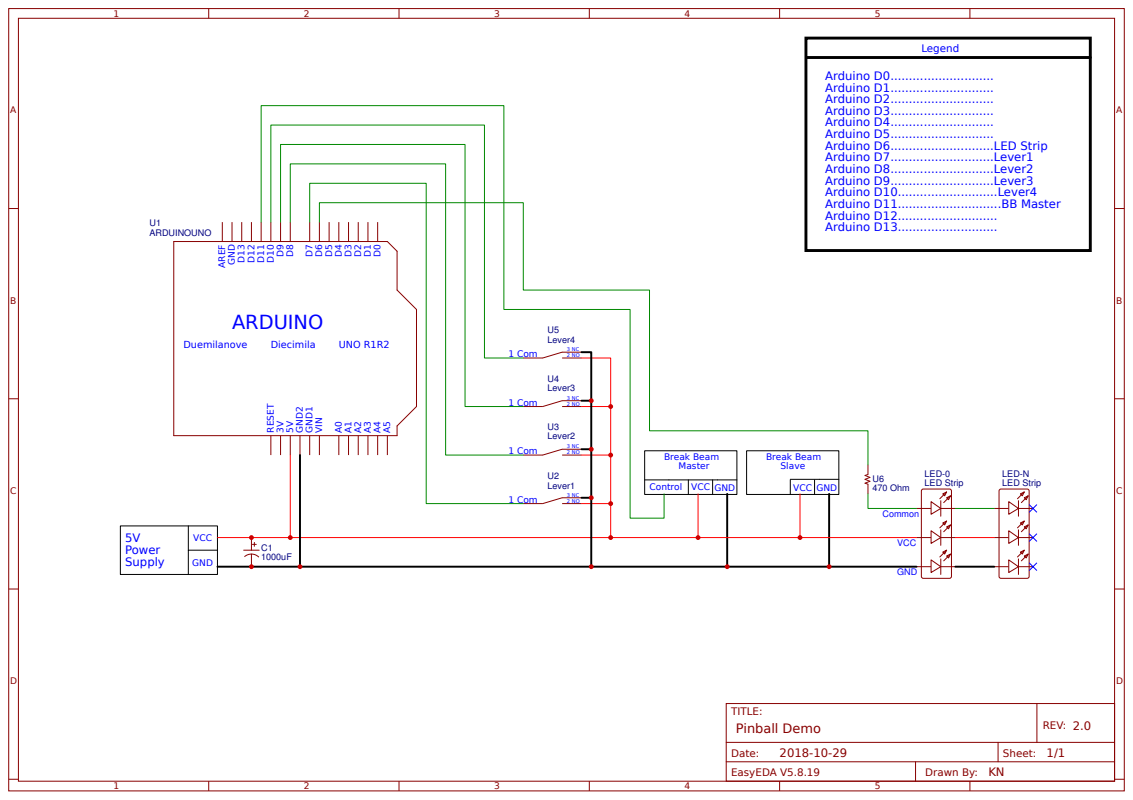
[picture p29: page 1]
TITLE:; Pinball Demo; REV: 2.0; Date:; Sheet: 1/1; EasyEDA V5.8.19; Drawn By: KN; ARDUINOUNO; ARDUINO; Duemilanove; Diecimila; UNO R1R2 D⁹D⁸; D⁷D⁶D⁵D⁴D³D²D¹D⁰ GND D¹³ D¹² D¹¹ D¹⁰ AREF; RESET 3V5VGND² GND¹ VIN; 5V Power Supply; Lever1; 1 Com; Lever2; Lever3; Lever4; Break Beam Master; Break Beam Slave; Legend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

5V

# Power

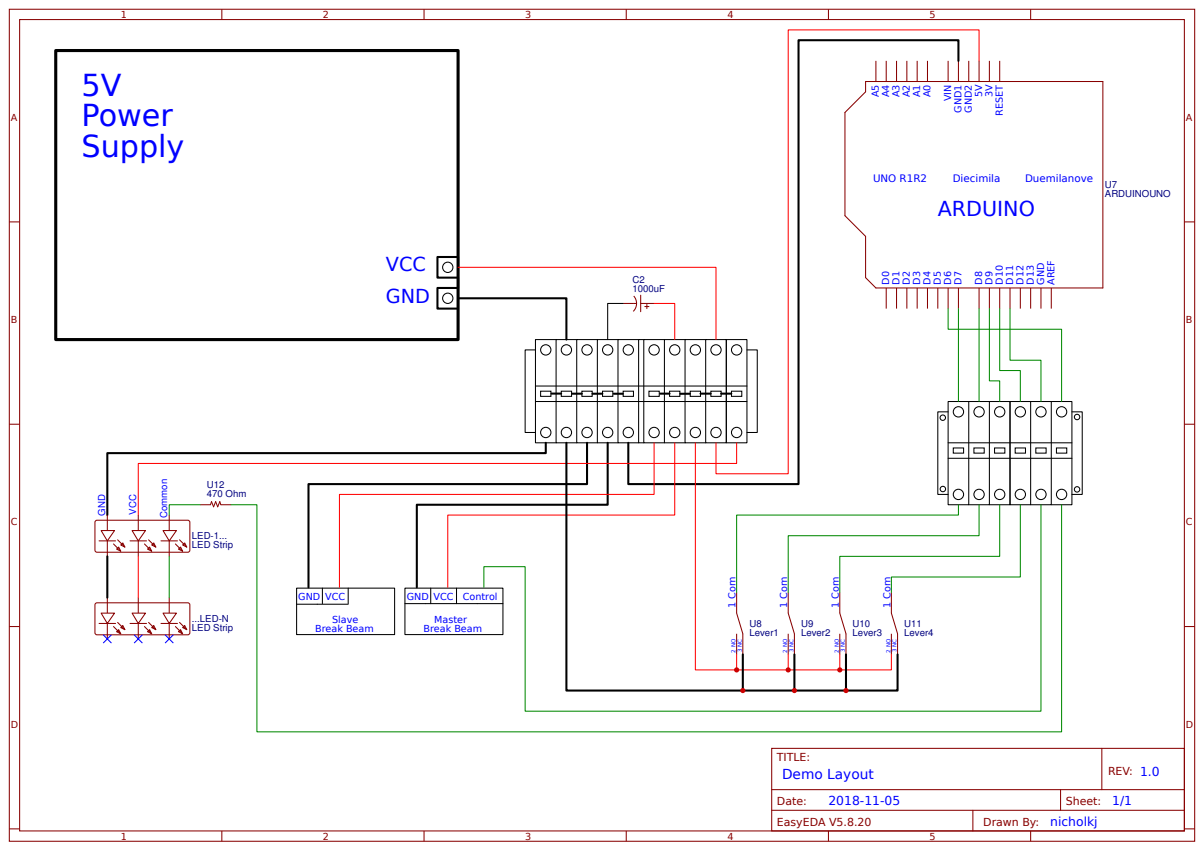
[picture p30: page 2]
TITLE:; Demo Layout; REV: 1.0; Date:; Sheet: 1/1; EasyEDA V5.8.20; Drawn By: nicholkj; Supply; ARDUINOUNO; ARDUINO; UNO R1R2; Diecimila; Duemilanove D⁰D¹D²D³D⁴D⁵D⁶D⁷; D⁸D⁹D¹⁰ D¹¹ D¹² D¹³ GND AREF A5A4A3A2A1A0; VIN GND¹ GND²5V3V RESET; VCC; GND; Lever1; 1 Com 2 NO; Lever2; Lever3; Lever4; Break Beam; Master; Slave; Control; LED Strip; LED-1...; ...LED-N; 470 Ohm; Common

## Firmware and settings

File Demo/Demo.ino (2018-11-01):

/*
Adafruit Arduino - Lesson 3. RGB LED
*/

int speakerPin = 12;
int redPin = 11;
int greenPin = 10;
int bluePin = 9;
int buttonPin = 2;
       
int buttonState;             // the current reading from the input pin
int lastButtonState = LOW;
int reading;

unsigned long lastDebounceTime = 0;  // the last time the output pin was toggled
unsigned long debounceDelay = 500;


void setup()
{
  pinMode(speakerPin, OUTPUT);
  pinMode(redPin, OUTPUT);
  pinMode(greenPin, OUTPUT);
  pinMode(bluePin, OUTPUT);
  pinMode(buttonPin, INPUT);  
}
 
void loop()
{
  reading = digitalRead(buttonPin);
  buttonState = digitalRead(buttonPin);

  if (reading != lastButtonState) 
  {
    // reset the debouncing timer
    lastDebounceTime = millis();
  }

  if ((millis() - lastDebounceTime) > debounceDelay) 
  {
    // whatever the reading is at, it's been there for longer than the debounce
    // delay, so take it as the actual current state:

    // if the button state has changed:
    if (reading != buttonState) 
    {
      buttonState = reading;


    if(buttonState == HIGH)
      {
    setColor(0,255,0);
    play();
      } 
      
    else
      {
    setColor(255,0,0);
    noTone(speakerPin);
       }
    }  
  }

  // save the reading. Next time through the loop, it'll be the lastButtonState:
  lastButtonState = reading;
}
 
void setColor(int red, int green, int blue)
{
  #ifdef COMMON_ANODE
    red = 255 - red;
    green = 255 - green;
    blue = 255 - blue;
  #endif
  analogWrite(redPin, red);
  analogWrite(greenPin, green);
  analogWrite(bluePin, blue);  
}

void play() {
  tone(speakerPin,554);
  delay(500);
  tone(speakerPin,622); 
  delay(500);
  tone(speakerPin,622); 
  delay(500);
  tone(speakerPin,698); 
  delay(500);
  tone(speakerPin,831);
  delay(500); 
  tone(speakerPin,740);
  delay(500);
  tone(speakerPin,698); 
  delay(500);
  tone(speakerPin,622); 
  delay(500);
  tone(speakerPin,554); 
  delay(500);
  tone(speakerPin,622); 
  delay(500);
  tone(speakerPin,-1); 
  delay(500);
  tone(speakerPin,415); 
  delay(500);
  tone(speakerPin,415);
}
 

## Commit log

2018-11-01 Arduino Demo code/folder
2018-11-13 Added STLs of current CAD files
    [BearingMount.stl, BreakBeamer.stl, BushingLower.stl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]
2019-05-29 Added Fusion 360 files
    [BallCatcher.f3d, BearingMount.stl, BreakBeamer.stl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]
